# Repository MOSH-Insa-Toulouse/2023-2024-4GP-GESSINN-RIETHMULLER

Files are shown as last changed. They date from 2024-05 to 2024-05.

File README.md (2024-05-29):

# Projet Capteur

## Description du projet

Ce projet a eu lieu dans le cadre de l'UF "du capteur au banc de test" en 4ème année de Génie physique à l'insa Toulouse. Le principe est d'établir une datasheet pour un capteur graphène soit une feuille de papier ou un tracé au crayon a papier est utilisé comme résistance.
Pour cela nous avons établis un banc de test avce differents composants arduino et avons utilisé le logiciel kikad pour créer un pcb pour les composants. Enfin nous avons éffectué des mesure pour déterminer la variation de la résistance en fonction du graphène et de la flexion du papier.
Nous avons utilisé un écran OLED sur le pcb pour choisir entre la mesure du capteur grapehène et d'un flex sensor et avons crée une application android pour avoir les valeurs de mesures sur le téléphone à l'aide d'une communication bluetooth.

Le Capteur ressemble à ça : 

Image capteur

## Livrables

* PCB shield pour arduino uno
* Code arduino
* Banc de test du capteur
* Application android qui fonctionne par bluetooth
* Datasheet

## Materiel Utilisé

* Ecran OLED
* Flex sensor
* Encodeur Rotatoire
* Capteur Graphène
* Module Bluetooth
* LCT-1050
* MCP 41050
* Résistances : 2x100kOhm, 1x33kOhm, 1*10kOhm, 1x1kOhm
* Capacités : 2x100nF, 1x1uF

## PCB Shield Pour Arduino Uno
### Partie Kikad
SHEMATIC

Nous avons commencé par mettre en place un shematic pour notre PCB. Pour cela, nous avons tout d'abord utilisé un template pour arduino uno et nous avons ensuite crée les empreintes et shematic pour chacun des composants sur notre plaque. Ensuite nous avons relié les entrées de chacun des composants aux entrées de l'arduino. Pour cela nous avons du faire des choix que l'on peut retrouver dans le document ci dessous :

https://github.com/MOSH-Insa-Toulouse/2023-2024-4GP-RIETHMULLER-GESSINN/blob/main/Projet%20Capteur%20composants.docx

Nous anvons ensuite procédé à l'organisation de la partie PCB. Nous avons disposé tout les elements sur la plaque et avons relié de façon à avoir un plan de masse sur la plaque et éviter d'avoir a faire des vias. Nous avons choisi d'avoir les pistes sur le dessus du PCB et d'avoir que des composants traverstants. Vous pouvez voir ci dessous le PCB à l'état fini.



### Impression du PCB 

Lorsque nous avions fini le PCB il fallait le réaliser. Avec l'aide de Catherine Crouzet nous avons imprimé notre plan de PCB et l'avons réalisé dans l'atelier du Batiment Génie Electrique. Nous avons ensuite percé la plaque à l'aide de forets de 1 ou 0.8 mm. Nous avons ensuite soudé les composant et ajouté des supports pour pouvoir déposer le PCB directement sur l'arduino UNO. Nous avons ensuite effectué des test de contact électrique de nos composants pour vérifier que tout était comme prévu et avons remarqué qu'il y avait une erreur.



Au niveau du premier point, deux pistes ne devant pas être relièes entraient en contact et au niveau du seconc, le plan de masse que devait être supposement relié à la masse ne l'était pas. Nous avons donc du remedier à ces problèmes avant de passer à la suite, pour cela nous avons bricolé pour éviter de devoir imprimer le PCB une seconde fois. Nous avons également corrigé cela sur le ficher Kikad qui se trouve sur le dossier en décalent simplement une réistance pour laisser l'espace nécessaire au plan de masse et au passage paralèlle des deux pistes.

## Code Arduino
Le code Arduino permet d'effectuer l'acquisition des mesures sur le capteur graphène et sur le flex sensor. Ces mesures sont a la fois affichées sur l'écran Oled et transmies au capteur bluetooth qui pourra les transmettre a un téléphone portable grace à l'application. Vous pouvez retrouver le code dans le dossier "Code Capteur Resistif ". Le code est annoté pour étre le plus lisible possible et suis les pins utilisés dans la partie KIKAD.
## Banc de test
Pour les tests nous avons utilisé le banc de tets à disposition et avons éffectué le mesures de la facon suivante :

ImageBanc

Il y 7 étages qui entrainent une déformation différente a chaque fois. Pour le capteur graphène nous avons mesuré pour chaque échelon la variation de resistance en tension et en déformation. Nous avons également réalisé des mesures sur le flex sensor afin de pouvoir comparer. Pour le flex sensor nous avons uniquement procédé en compression car celui-ci n'est fiable que dans un sens.

Les résusltats de nos mesures sont à retrouver dans la partie Datasheet.

## Application android

Pour la conception de notre application, nous avons utilisé le site MIP App Inventor, le but étant d'avoir accès au résultats de nos mesures sur un téléphone par communication Bluetooth. Pour cela nous avons utilisé un "Listpicker" pour connecter l'appareil au téléphone.
Nous avons ensuite utilisé le module bluetooth pour récuperer 2 messages de 1 octet chacun. Nous avons utilisé un clock pour calibrer l'intervale entre les mesures recues afin d'avoir le même que dans le code. Pour finir nous avons effectué du traitement de données afin d'avoir la variation de la résistance ainsi que les deux valeurs de resistance. Le code donne ceci:



Comme on peut le voir dans les blocks nous avons utilisé plusieurs variables globales notamment pour les calculs de la résistance du flex sensor. Nous avons également multiplié toutes les mesures recues par 4 car nous les avions divisées par 4 dans le code arduino pour que chaque mesure passe dans un octet. 

Pour ce qui est de la face avant, nous avons choisis un interface relativement simple: 


Nous avons un bouton de connexion Bluetooth qui permet de choisir l'appareil à connecter. Nous avons ensuite ajouté des boutons d'arrêt de clock pour pouvoir stopper l'arrivée des mesures si souhaité. Le reste de l'interface est uniquement de l'affichage des mesures.

## Datasheet
Nos avons réalisé de mesures en utilisant differentes valeurs de déformation et nous avons utilisé des crayons à mine H, HB et 2B.
Nous avons également réalisé de mesures sur le flex sensor en compression.
On peut voir d'abord les mesures en compression :



Et ensuite les mesures en tension : 



## Contacts

Pour toute remarque ou information complémentaire, n'hésitez pas à nous contacter :
* Clément GESSINN : cgessinn@insa-toulouse.fr
* Théo RIETHMULLER : riethmul@insa-toulouse.fr

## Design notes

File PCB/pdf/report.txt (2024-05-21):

Plotted to 'U:\TPMOSH\Projet-capteurs\PCB\Template Uno.pdf'.

Info: Done.

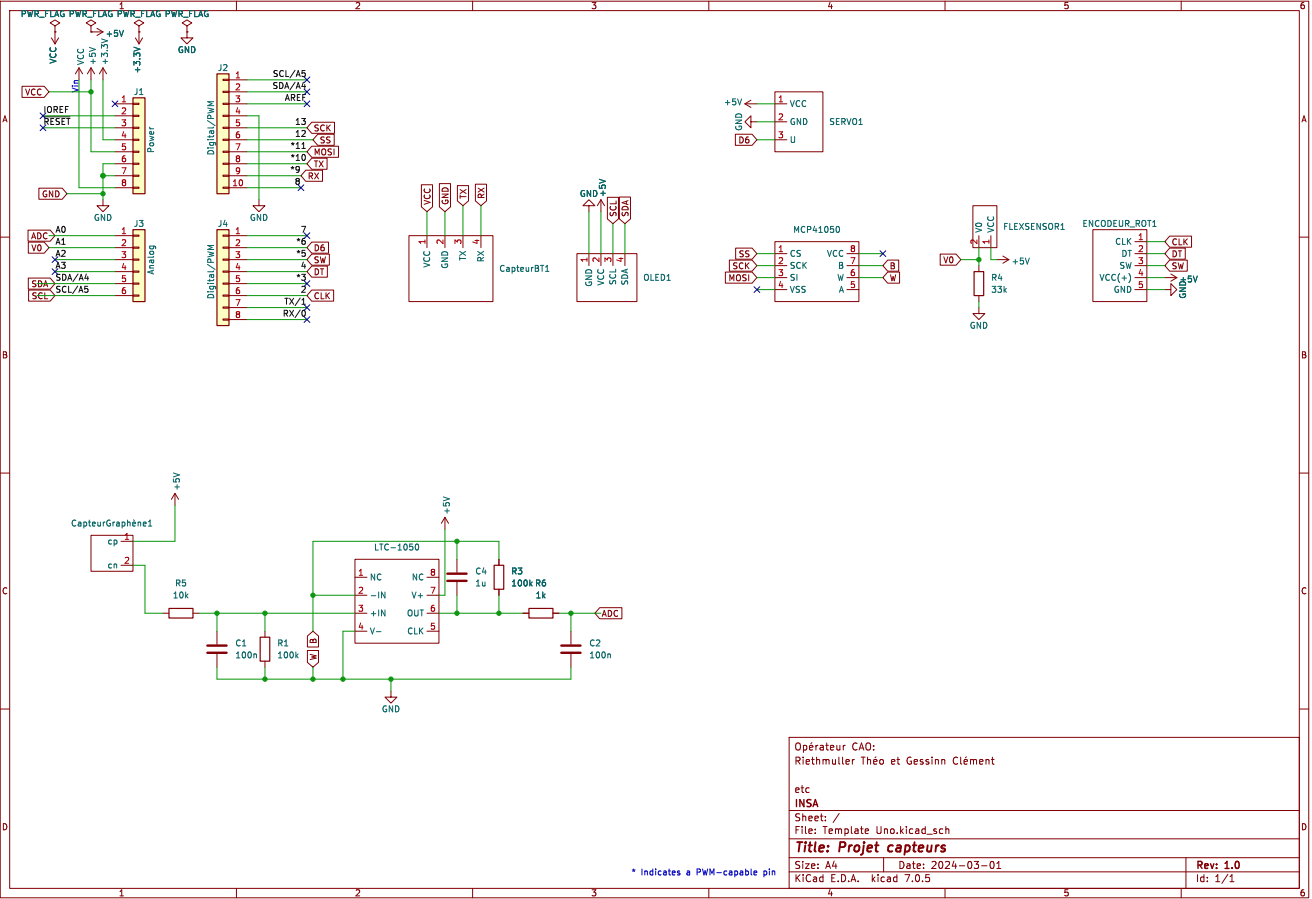
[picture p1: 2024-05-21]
PCB/pdf/SHEMATIC.PNG

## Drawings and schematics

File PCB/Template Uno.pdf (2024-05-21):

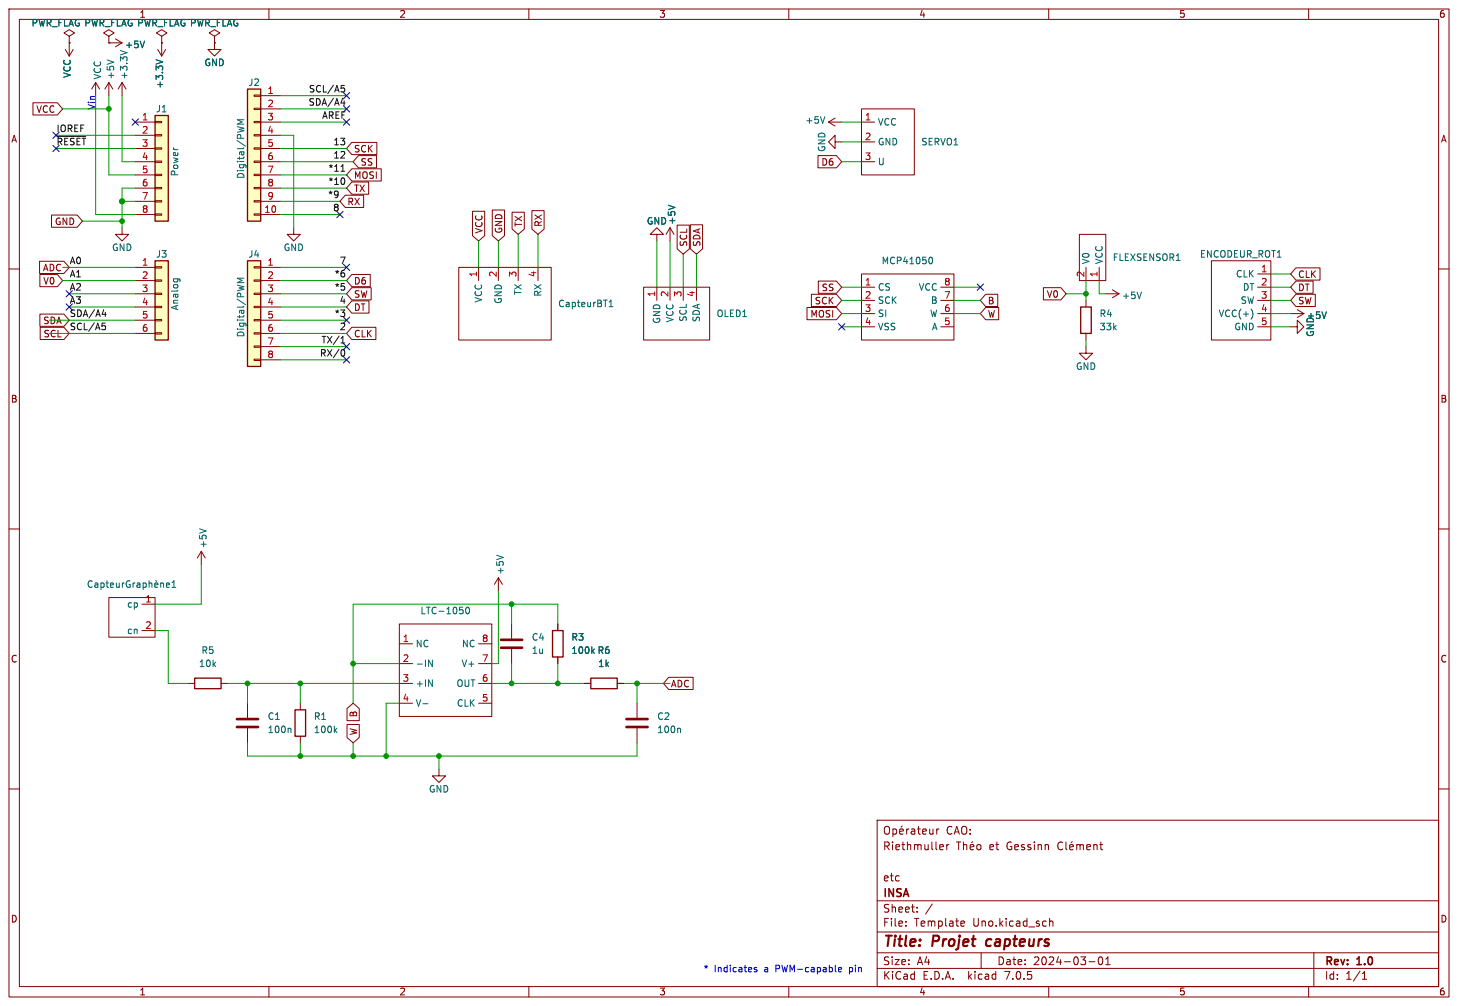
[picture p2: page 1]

2 RX/0 TX/1 SCL/A5 SDA/A4 A2A3A1A0 Vin

INSA
File: Template Uno.kicad_sch Sheet: /
Id: 1/1 Title: Projet capteurs

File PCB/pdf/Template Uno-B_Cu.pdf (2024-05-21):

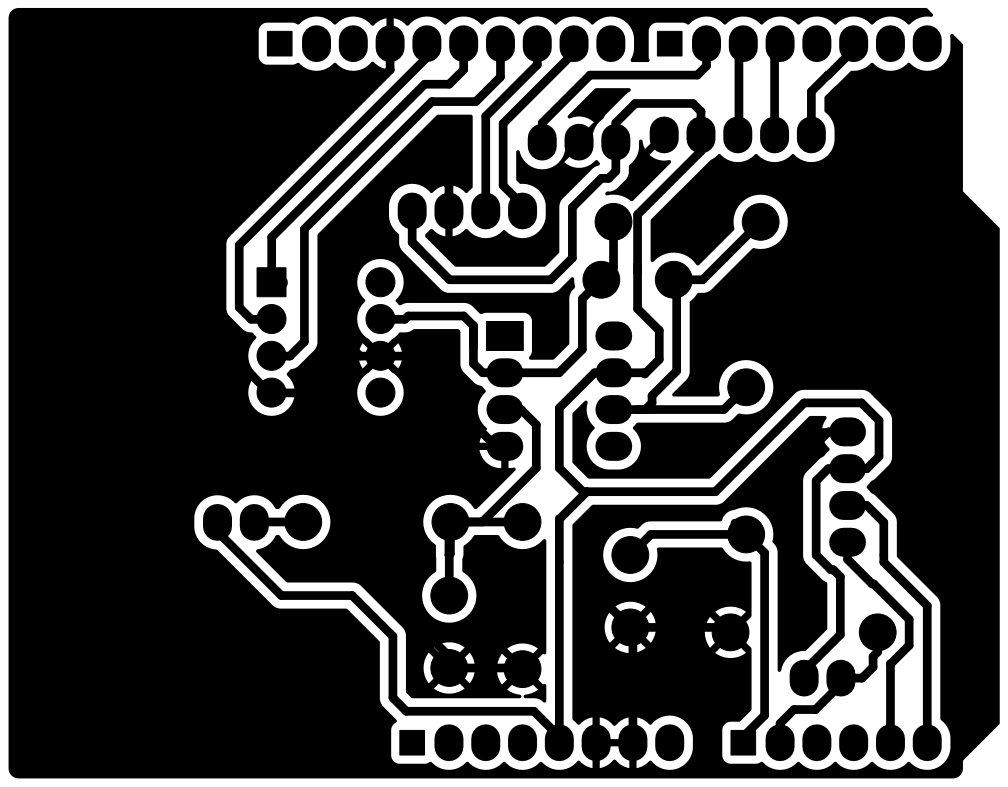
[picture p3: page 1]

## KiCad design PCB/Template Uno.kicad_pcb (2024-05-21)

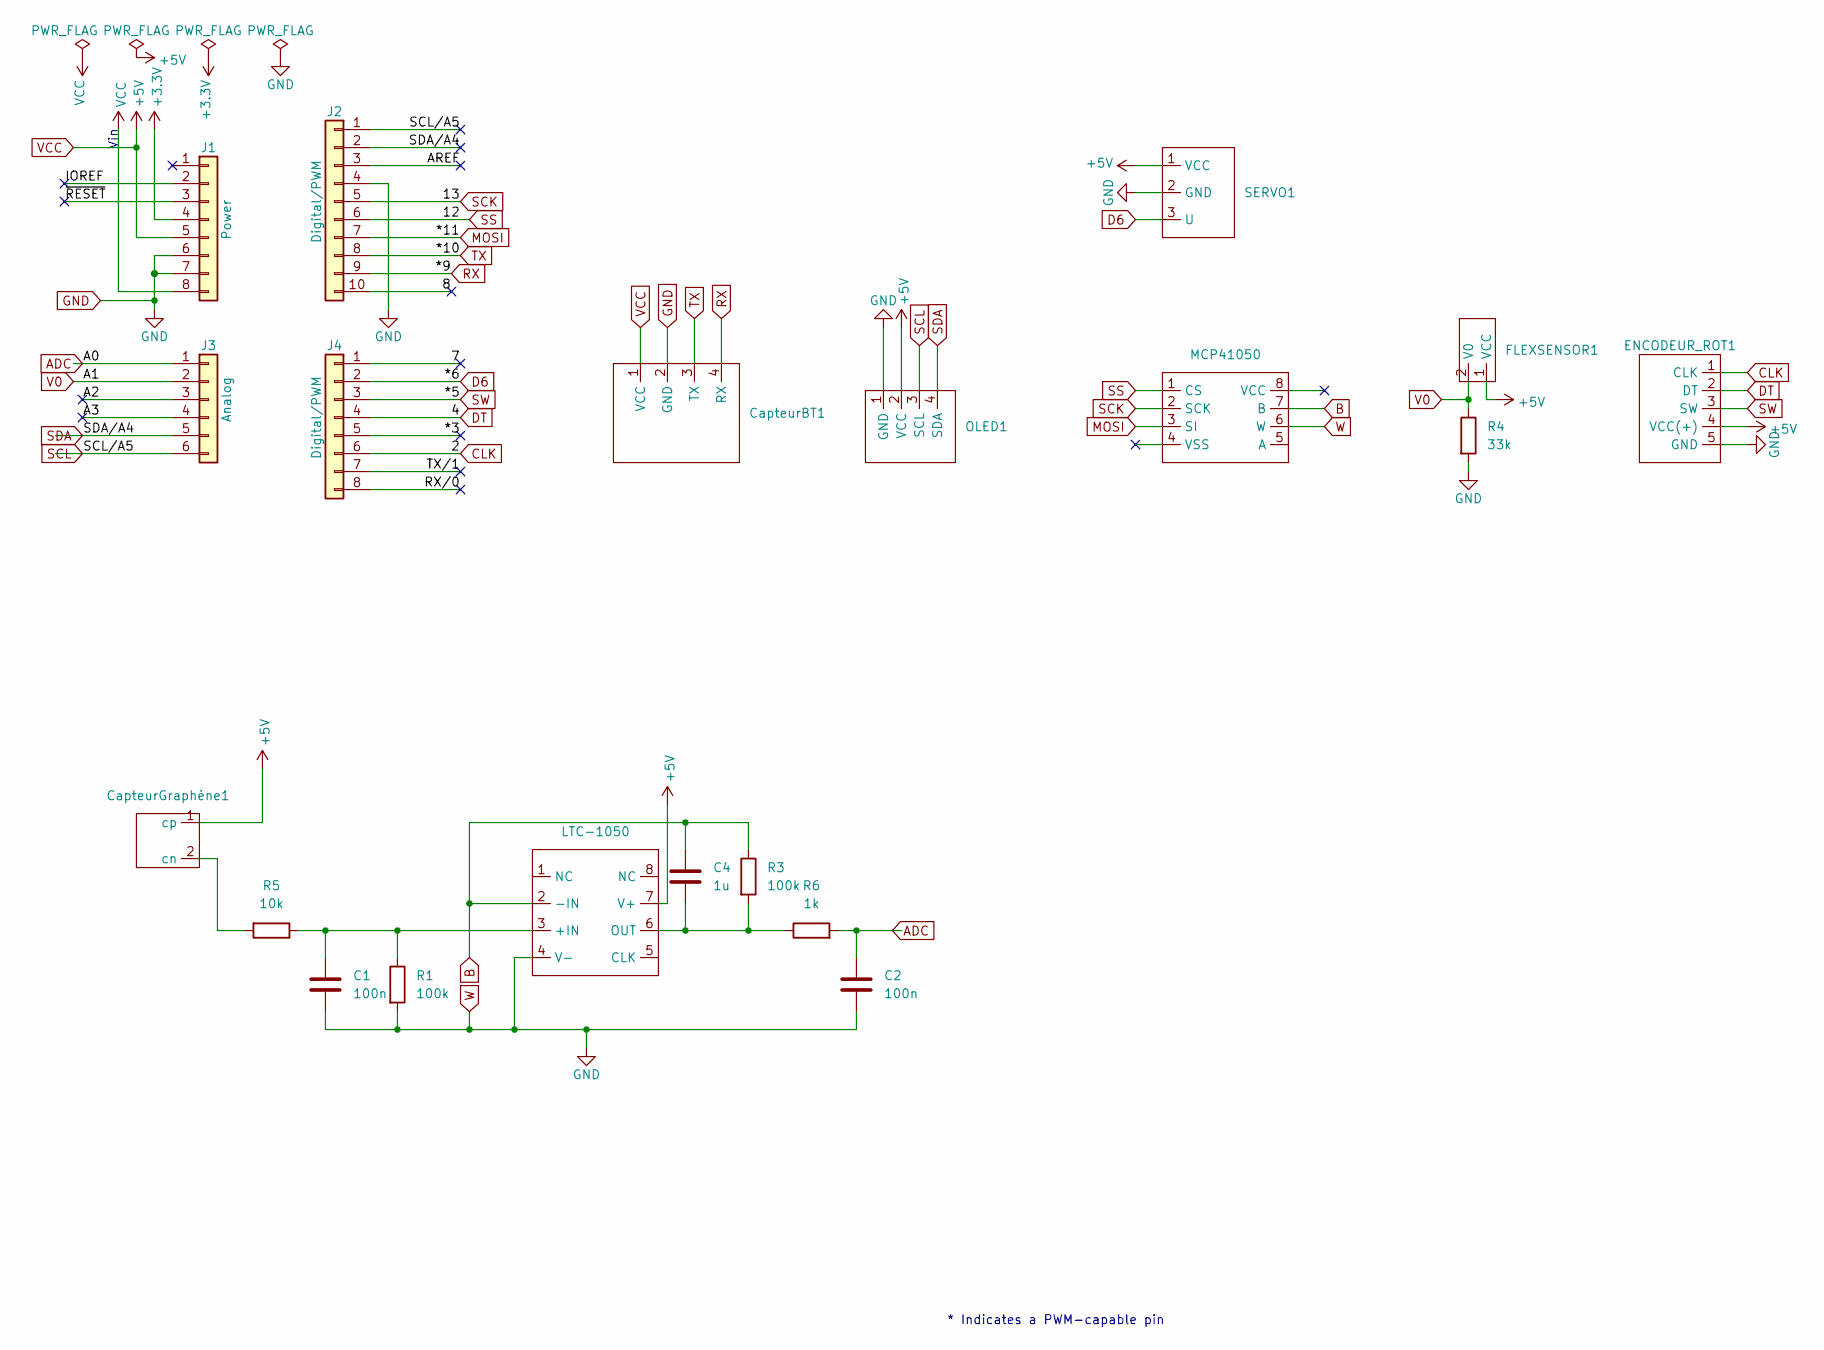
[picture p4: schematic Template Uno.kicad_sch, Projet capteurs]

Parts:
C1, C2: 100n; C_Disc_D5.1mm_W3.2mm_P5.00mm
C4: 1u; C_Rect_L7.0mm_W3.5mm_P5.00mm
CapteurBT1: BT
CapteurGraphène1: CAPTEUR GRAPHENE
ENCODEUR_ROT1: ENCODEUR KY-040
FLEXSENSOR1: FLEX SENSOR
J1: Power; PinSocket_1x08_P2.54mm_Vertical
J2: Digital/PWM; PinSocket_1x10_P2.54mm_Vertical
J3: Analog; PinSocket_1x06_P2.54mm_Vertical
J4: Digital/PWM; PinSocket_1x08_P2.54mm_Vertical
LTC-1050: LTC-1050
MCP41050: POTENTIOMETRE DIGITAL
OLED1: OLED
R1, R3: 100k; R_Axial_DIN0207_L6.3mm_D2.5mm_P10.16mm_Horizontal
R4: 33k; R_Axial_DIN0207_L6.3mm_D2.5mm_P10.16mm_Horizontal
R5: 10k; R_Axial_DIN0207_L6.3mm_D2.5mm_P10.16mm_Horizontal
R6: 1k; R_Axial_DIN0207_L6.3mm_D2.5mm_P10.16mm_Horizontal
SERVO1: SERVO

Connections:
+3V3: J1.4
/7: J4.1
/8: J2.10
/*3: J4.5
/A2: J3.3
/A3: J3.4
/AREF: J2.3
/IOREF: J1.2
/RX/0: J4.8
/TX/1: J4.7
/~RESET: J1.3
ADC: C2.1, J3.1, R6.2
B: C4.1, LTC-1050.2 (-IN), MCP41050.7 (B), R3.1
CLK: ENCODEUR_ROT1.1 (CLK), J4.6
D6: J4.2, SERVO1.3 (U)
DT: ENCODEUR_ROT1.2 (DT), J4.4
GND: C1.2, C2.2, CapteurBT1.2 (GND), ENCODEUR_ROT1.5 (GND), J1.6, J1.7, J2.4, LTC-1050.4 (V-), MCP41050.6 (W), OLED1.1 (GND), R1.2, R4.2, SERVO1.2 (GND)
MOSI: J2.7, MCP41050.3 (SI)
unnamed: CapteurGraphène1.2 (cn), R5.2
unnamed: C1.1, LTC-1050.3 (+IN), R1.1, R5.1
unnamed: C4.2, LTC-1050.6 (OUT), R3.2, R6.1
RX: CapteurBT1.4 (RX), J2.9
SCK: J2.5, MCP41050.2 (SCK)
SCL: J2.1, J3.6, OLED1.3 (SCL)
SDA: J2.2, J3.5, OLED1.4 (SDA)
SS: J2.6, MCP41050.1 (CS)
SW: ENCODEUR_ROT1.3 (SW), J4.3
TX: CapteurBT1.3 (TX), J2.8
V0: FLEXSENSOR1.2 (V0), J3.2, R4.1
VCC: CapteurBT1.1 (VCC), CapteurGraphène1.1 (cp), ENCODEUR_ROT1.4 (VCC(+)), FLEXSENSOR1.1 (VCC), J1.5, J1.8, LTC-1050.7 (V+), OLED1.2 (VCC), SERVO1.1 (VCC)

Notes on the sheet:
Vin
* Indicates a PWM-capable pin

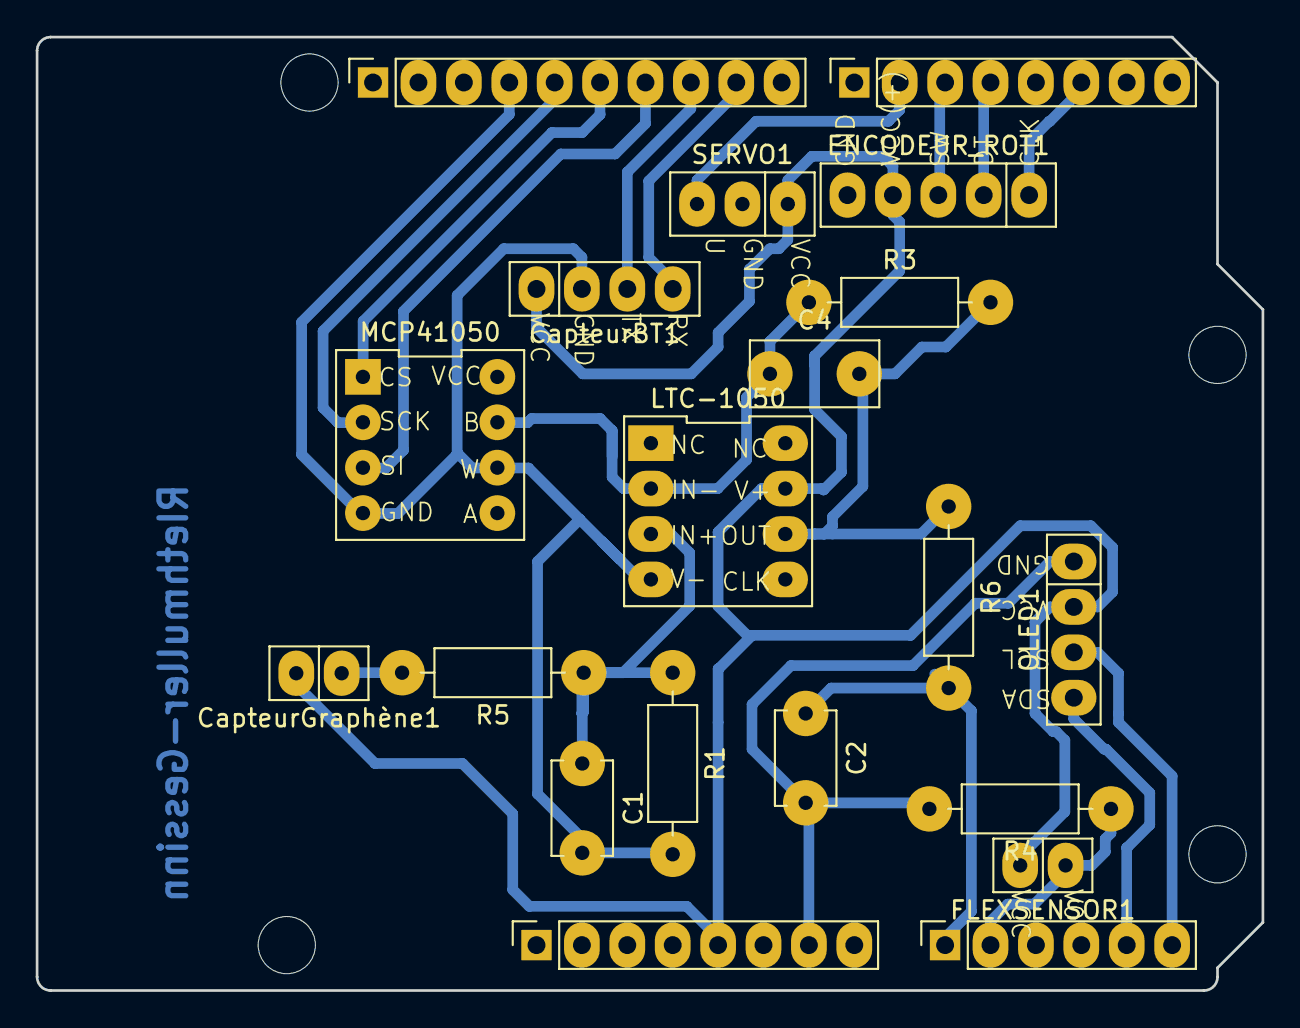
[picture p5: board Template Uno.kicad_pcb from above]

Board: 2 copper layers, 68.6 x 53.3 mm, 24 parts (0 on the bottom side), 19 nets.

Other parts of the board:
MH1, MH2, MH3, MH4: MountingHole_3.2mm

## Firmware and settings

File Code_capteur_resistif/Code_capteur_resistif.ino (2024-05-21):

// ========= CODE CAPTEUR RESISTIF ========= //


// *********************************************************//
// *********************************************************//


// ========= Initialisation ecran OLED ========= //

#include <Adafruit_SSD1306.h>

#define nombreDePixelsEnLargeur 128         // Taille de l'écran OLED, en pixel, au niveau de sa largeur
#define nombreDePixelsEnHauteur 64          // Taille de l'écran OLED, en pixel, au niveau de sa hauteur
#define brocheResetOLED         -1          // Reset de l'OLED partagé avec l'Arduino (d'où la valeur à -1, et non un numéro de pin)
#define adresseI2CecranOLED     0x3C        // Adresse de "mon" écran OLED sur le bus i2c (généralement égal à 0x3C ou 0x3D)

Adafruit_SSD1306 ecranOLED(nombreDePixelsEnLargeur, nombreDePixelsEnHauteur, &Wire, brocheResetOLED);

// ========= Initialisation flex sensor ========= //

const int flexPin = A1;
const float VCC = 5;      // voltage at Arduino 5V line
const float R_DIV = 33000.0;  // resistor used to create a voltage divider
const float flatResistance = 25000.0; // resistance when flat
const float bendResistance = 100000.0; // resistance at 90 deg

// ========= Initialisation encodeur rotatoire ========= //

#define encoder0PinA  2  //CLK Output A Do not use other pin for clock as we are using interrupt
#define encoder0PinB  4  //DT Output B
#define Switch 5 // Switch connection if available

volatile unsigned int encoder0Pos = 0;

void doEncoder() {
  if (digitalRead(encoder0PinA)==HIGH && digitalRead(encoder0PinB)==HIGH) {
    encoder0Pos++;
    delay(500);
  } else if (digitalRead(encoder0PinA)==HIGH && digitalRead(encoder0PinB)==LOW) {
    encoder0Pos--;
    delay(500);
  }
}

// ========= Initialisation potentiometre digital ========= //

#include <SPI.h>

const byte csPin           = 12;      // MCP42100 chip select pin
const int  maxPositions    = 256;     // wiper can move from 0 to 255 = 256 positions
const long rAB             = 46000;   // 46k pot resistance between terminals A and B 
const byte rWiper          = 125;     // 125 ohms pot wiper resistance
const byte pot0            = 0x11;    // pot0 addr // B 0001 0001
const byte pot0Shutdown    = 0x21;    // pot0 shutdown // B 0010 0001

void setPotWiper(int addr, int pos) {
  pos = constrain(pos, 0, 255);            // limit wiper setting to range of 0 to 255
  digitalWrite(csPin, LOW);                // select chip
  SPI.transfer(addr);                      // configure target pot with wiper position
  SPI.transfer(pos);
  digitalWrite(csPin, HIGH);               // de-select chip

  long resistanceWB = ((rAB * pos) / maxPositions ) + rWiper;     // print pot resistance between wiper and B terminal
  Serial.print("Wiper position : ");
  Serial.print(pos);
  Serial.print(" Resistance wiper to B terminal : ");
  Serial.print(resistanceWB);
  Serial.println(" ohms");
}

// ========= Initialisation module bluetooth ========= //

#include <SoftwareSerial.h>
#define rxPin 10     //Broche 10 en tant que RX, a raccorder sur TX du HC05-07
#define txPin 9     //Broche 9 en tant que TX, a raccorder sur RX du HC05-07
#define baudrate 9600
SoftwareSerial mySerial(rxPin ,txPin);     //Definition du software serial


// *********************************************************//
// *********************************************************//


void setup() {
  
  Serial.begin(9600);

  // ========= Setup ecran OLED ========= //

  ecranOLED.begin(SSD1306_SWITCHCAPVCC, adresseI2CecranOLED);
  ecranOLED.setTextSize(1);
  ecranOLED.setTextColor(SSD1306_WHITE);

  // ========= Setup flex sensor ========= //

  pinMode(flexPin, INPUT);

  // ========= Setup encodeur rotatoire ========= //

  pinMode(encoder0PinA, INPUT);
  digitalWrite(encoder0PinA, HIGH);
  pinMode(encoder0PinB, INPUT);
  digitalWrite(encoder0PinB, HIGH);
  attachInterrupt(0, doEncoder, RISING);
  Serial.println("start");

  // ========= Setup potentiometre digital ========= //

  digitalWrite(csPin, HIGH);        // chip select default to de-selected
  pinMode(csPin, OUTPUT);           // configure chip select as output
  SPI.begin();
  //setPotWiper(pot0, 255);     // réglage de la valeur de resistance de R2
  //delay(500);

  // ========= Setup module bluetooth ========= //

  pinMode(rxPin,INPUT);
  pinMode(txPin,OUTPUT);
    
  mySerial.begin(baudrate);
  Serial.begin(baudrate);
}


// *********************************************************//
// *********************************************************//


void loop() {

  int sensorValue = analogRead(A0);     // on recupere la valeur de resistance du capteur graphene
  //Serial.print("Resistance_graphene : ");
  Serial.println(sensorValue);
  ecranOLED.clearDisplay();
  ecranOLED.setCursor(0, 10);
  ecranOLED.println("RESISTANCE GRAPHENE");
  ecranOLED.println(sensorValue);
  delay(500);

  int ADCflex = analogRead(flexPin);     // on recupere la valeur brute du flex sensor
  float Vflex = ADCflex * VCC / 1023.0;     // on convertit cette valeur brute en tension reelle
  float Rflex = R_DIV * (VCC / Vflex - 1.0);     // on calcule la resistance correspondante du flex sensor
  //Serial.print("Resistance_flex : ");
  Serial.println(String(Rflex) + " ohms");
  ecranOLED.println("RESISTANCE FLEXSENSOR");
  ecranOLED.println(Rflex);
  ecranOLED.display();
  delay(500);

  //Serial.print("Position : ");
  Serial.println (encoder0Pos, DEC);  //Angle = (360 / Encoder_Resolution) * encoder0Pos
  delay(500);

  mySerial.write(sensorValue/4);     // on envoie vers le module bluetooth la donnee mesuree divisee par 4 car on passe de 10 bits (1024 valeurs) a 8 bits (256 valeurs)
  mySerial.write(ADCflex/4);     // on envoie vers le module bluetooth la donnee mesuree divisee par 4 car on passe de 10 bits (1024 valeurs) a 8 bits (256 valeurs)
}
